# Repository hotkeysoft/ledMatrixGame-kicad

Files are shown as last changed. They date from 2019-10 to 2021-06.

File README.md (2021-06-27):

# LED Matrix Game
Rev A October 2019

### Handheld Electronic Game
- ATmega328PB microcontroller running at 12MHz
- 53 LEDs
- 6 push buttons
- Buzzer
- Tag-Connect for programming
- Runs on 3 AAA batteries

The microcontroller runs a [TMS1000-series emulator](https://github.com/hotkeysoft/emulators) I made.

The Split Second game (by *Parker Brothers*) TMS1400 ROM is loaded on the emulator.

Images
============
|Front | Back |
|---|---|
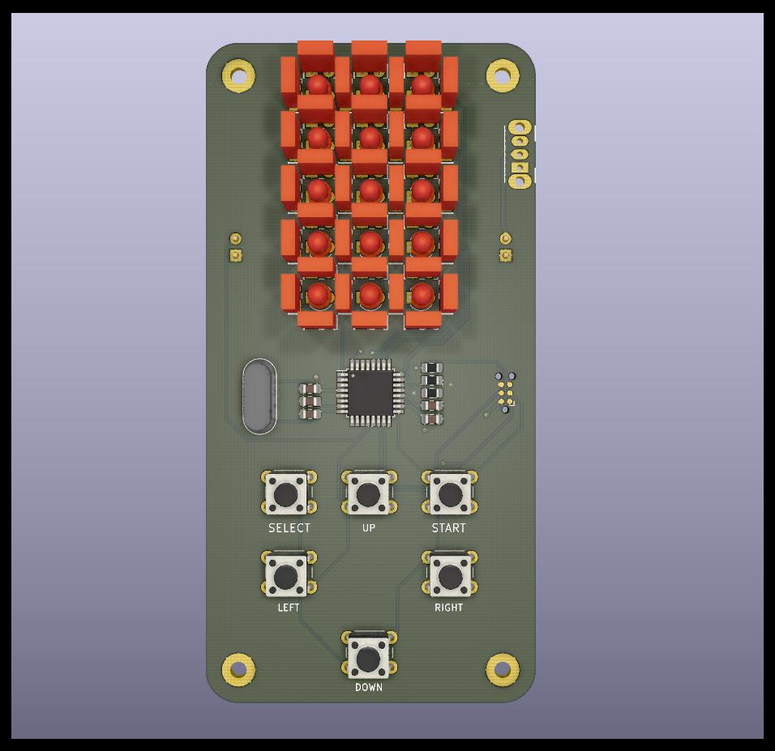
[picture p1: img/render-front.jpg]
Render Front
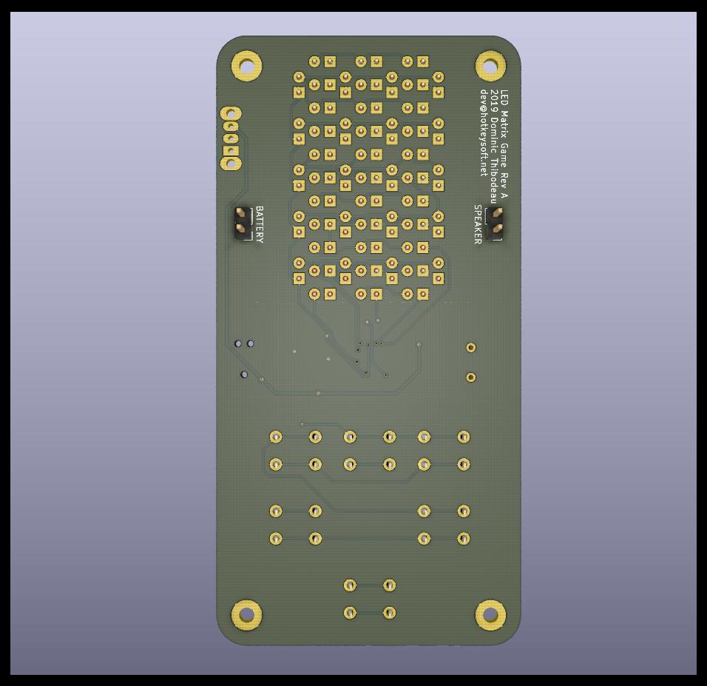
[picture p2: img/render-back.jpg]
Render Back
|||

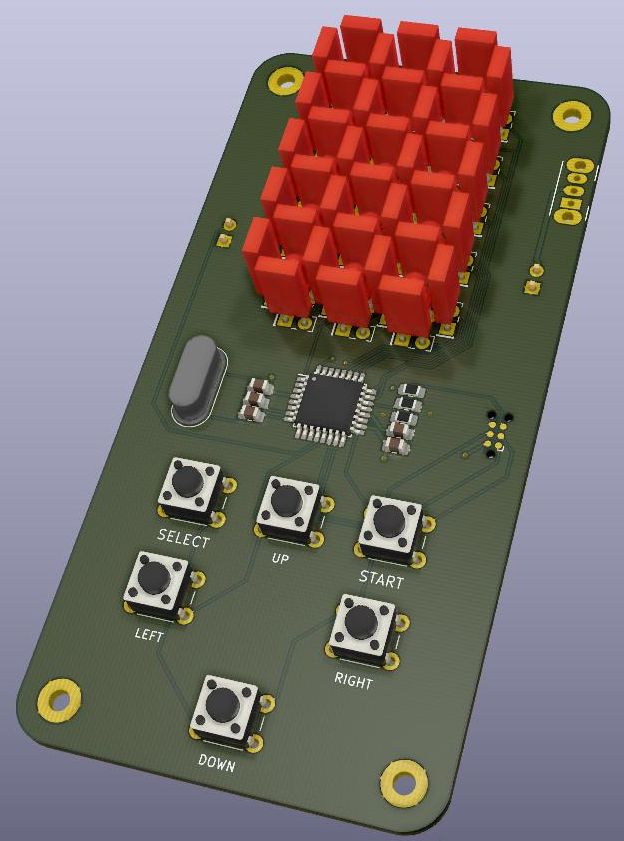
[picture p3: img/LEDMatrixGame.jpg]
Render


### Schematics (pdf)
- [Complete schematics](./img/schema.pdf)

### PCB Images (svg)
- [Top](./img/pcb-front.svg)
- [Bottom](./img/pcb-back.svg)

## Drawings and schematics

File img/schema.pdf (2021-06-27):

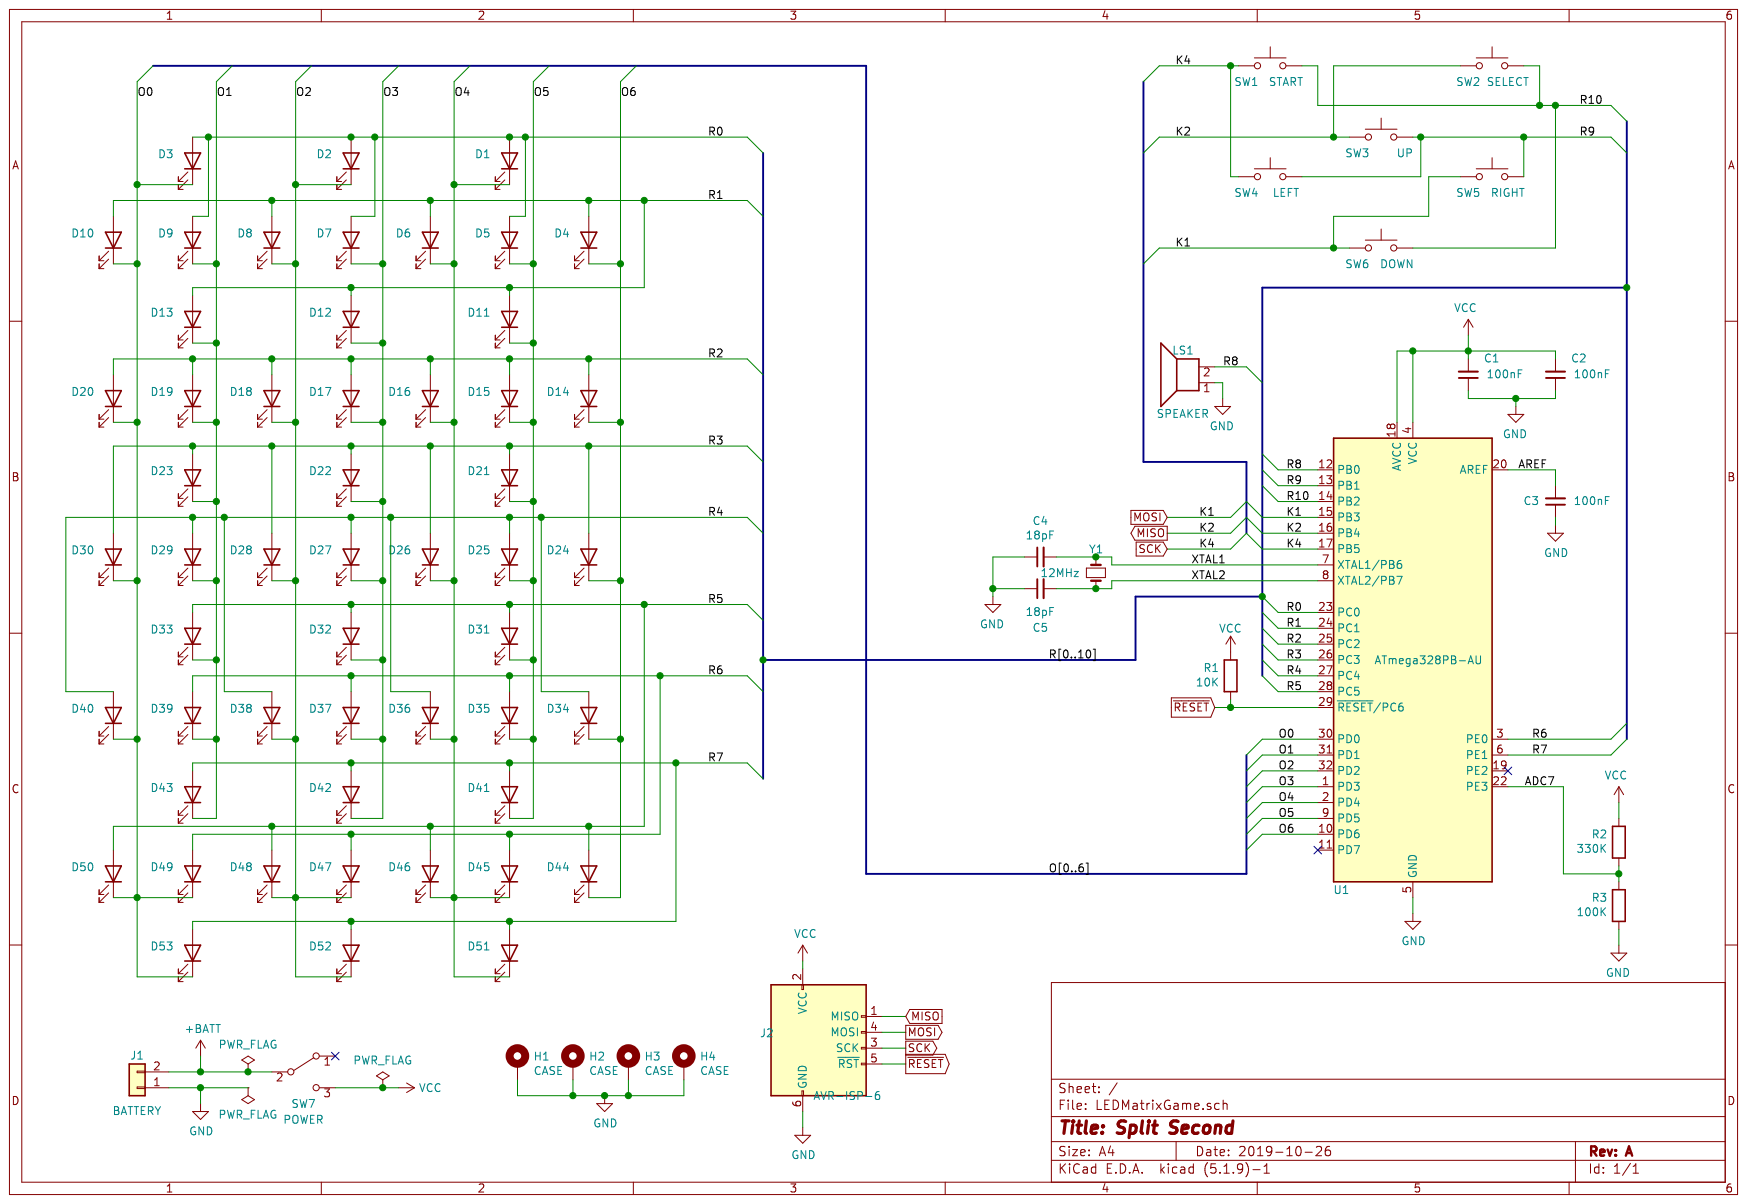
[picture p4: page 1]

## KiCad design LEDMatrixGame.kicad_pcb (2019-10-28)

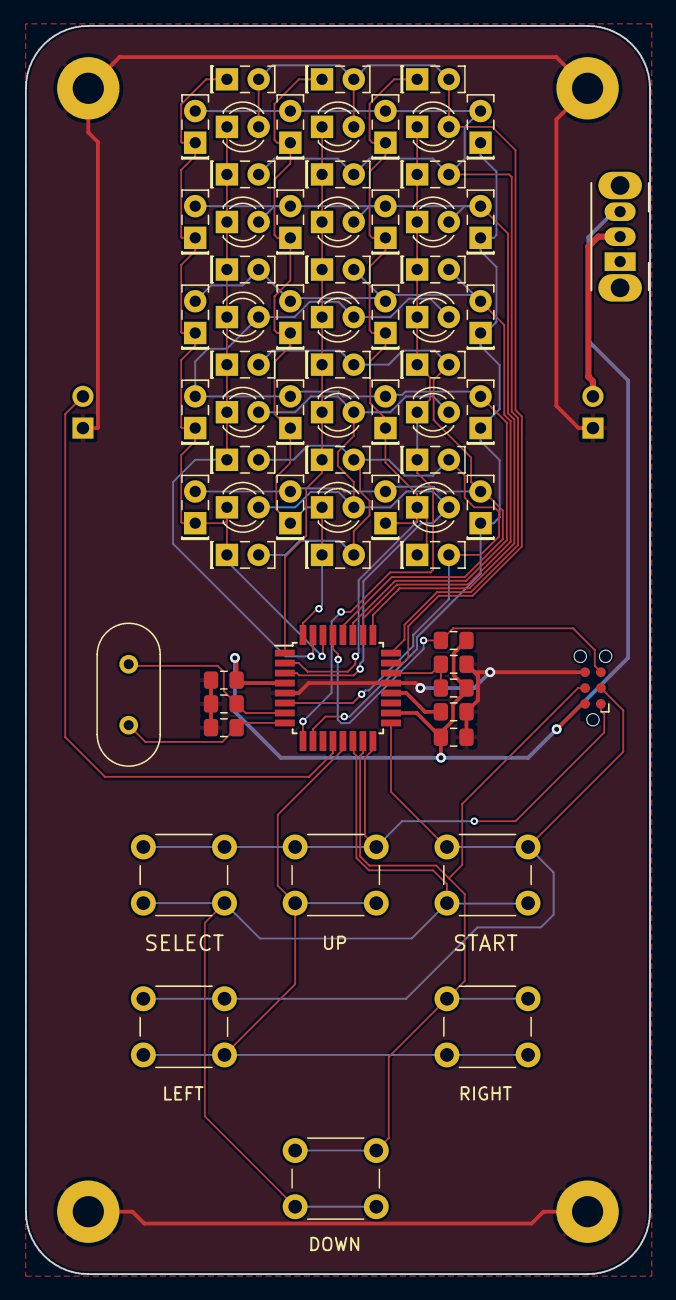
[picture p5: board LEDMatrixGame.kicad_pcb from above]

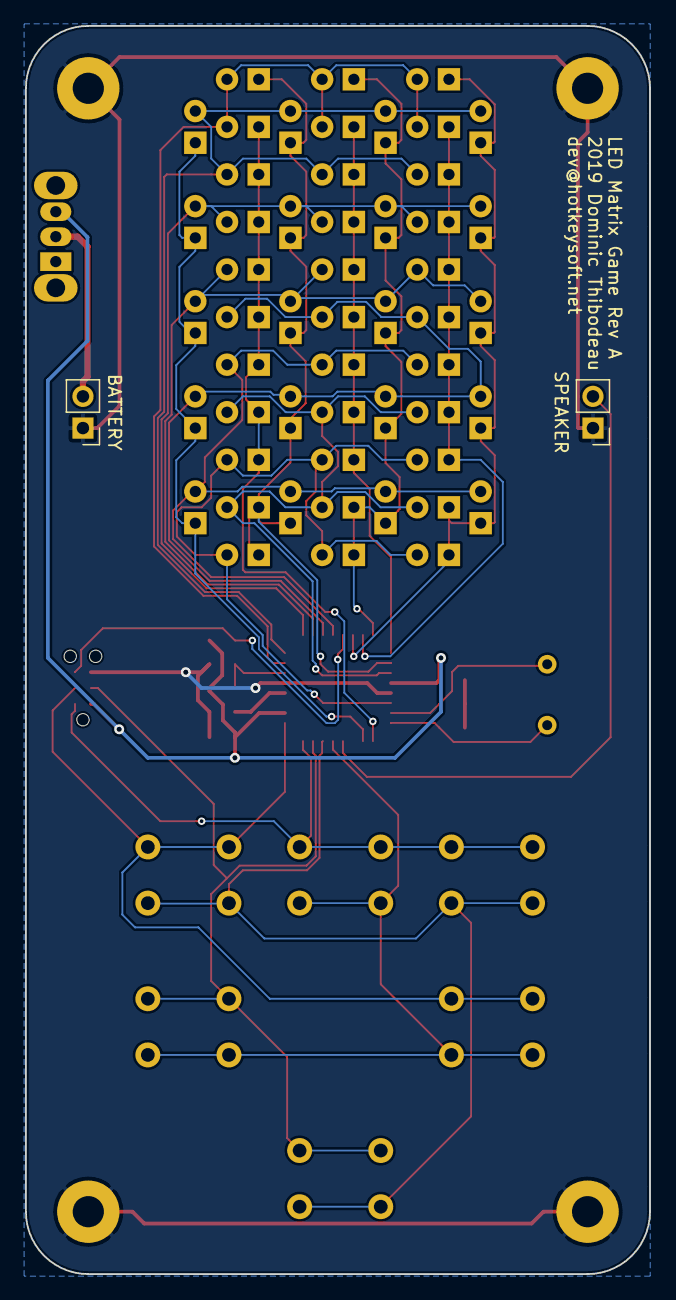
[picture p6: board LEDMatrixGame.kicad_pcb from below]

Board: 2 copper layers, 50.0 x 100.0 mm, 77 parts (2 on the bottom side), 29 nets.

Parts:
C1, C2, C3: 100nF; C_0805_2012Metric_Pad1.15x1.40mm_HandSolder
C4, C5: 18pF; C_0805_2012Metric_Pad1.15x1.40mm_HandSolder
D1, D2, D3, D4, D6, D8, D10, D11, D12, D13, D14, D16, D18, D20, D21, D22, D23, D24, D26, D28, D30, D31, D32, D33, D34, D36, D38, D40, D41, D42, D43, D44, D46, D48, D50, D51, D52, D53: LED_Rectangular_W5.0mm_H2.0mm
D5, D7, D9, D15, D17, D19, D25, D27, D29, D35, D37, D39, D45, D47, D49: LED_D3.0mm
H1, H2, H3, H4: CASE; MountingHole_2.5mm_Pad
J1: BATTERY; PinHeader_1x02_P2.54mm_Vertical
J2: AVR-ISP-6; Tag-Connect_TC2030-IDC-NL_2x03_P1.27mm_Vertical
LS1: SPEAKER; PinHeader_1x02_P2.54mm_Vertical
R1: 10K; R_0805_2012Metric_Pad1.15x1.40mm_HandSolder
R2: 330K; R_0805_2012Metric_Pad1.15x1.40mm_HandSolder
R3: 100K; R_0805_2012Metric_Pad1.15x1.40mm_HandSolder
SW1: START; SW_PUSH_6mm_H5mm
SW2: SELECT; SW_PUSH_6mm_H5mm
SW3: UP; SW_PUSH_6mm_H5mm
SW4: LEFT; SW_PUSH_6mm_H5mm
SW5: RIGHT; SW_PUSH_6mm_H5mm
SW6: DOWN; SW_PUSH_6mm_H5mm
SW7: POWER; SW_CuK_OS102011MA1QN1_SPDT_Angled
U1: ATmega328PB-AU; TQFP-32_7x7mm_P0.8mm
Y1: 12MHz; Crystal_HC49-4H_Vertical

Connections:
+BATT: J1.2, SW7.2
/ADC7: R2.1, R3.2, U1.22
/AREF: C3.2, U1.20
/O0: D3.1, D10.1, D20.1, D30.1, D40.1, D49.1, D50.1, D53.1, U1.30
/O1: D9.1, D13.1, D19.1, D23.1, D29.1, D33.1, D39.1, D43.1, U1.31
/O2: D2.1, D8.1, D18.1, D28.1, D38.1, D47.1, D48.1, D52.1, U1.32
/O3: D7.1, D12.1, D17.1, D22.1, D27.1, D32.1, D37.1, D42.1, U1.1
/O4: D1.1, D6.1, D16.1, D26.1, D36.1, D45.1, D46.1, D51.1, U1.2
/O5: D5.1, D11.1, D15.1, D21.1, D25.1, D31.1, D35.1, D41.1, U1.9
/O6: D4.1, D14.1, D24.1, D34.1, D44.1, U1.10
/R0: D1.2, D2.2, D3.2, D5.2, D7.2, D9.2, U1.23
/R1: D4.2, D6.2, D8.2, D10.2, D11.2, D12.2, D13.2, U1.24
/R2: D14.2, D15.2, D16.2, D17.2, D18.2, D19.2, D20.2, U1.25
/R3: D21.2, D22.2, D23.2, D24.2, D26.2, D28.2, D30.2, U1.26
/R4: D25.2, D27.2, D29.2, D34.2, D36.2, D38.2, D40.2, U1.27
/R5: D31.2, D32.2, D33.2, D44.2, D46.2, D48.2, D50.2, U1.28
/R6: D35.2, D37.2, D39.2, D45.2, D47.2, D49.2, U1.3
/R7: D41.2, D42.2, D43.2, D51.2, D52.2, D53.2, U1.6
/R8: LS1.2, U1.12
/R9: SW3.2, SW4.2, SW5.2, U1.13
/R10: SW1.2, SW2.2, SW6.2, U1.14
/XTAL1: C4.2, U1.7, Y1.1
/XTAL2: C5.2, U1.8, Y1.2
GND: C1.1, C2.1, C3.1, C4.1, C5.1, H1.1, H2.1, H3.1, H4.1, J1.1, J2.6, LS1.1, R3.1, U1.5, U1.21
MISO: J2.1, SW2.1, SW3.1, U1.16
MOSI: J2.4, SW5.1, SW6.1, U1.15
SCK: J2.3, SW1.1, SW4.1, U1.17
VCC: C1.2, C2.2, J2.2, R1.2, R2.2, SW7.3, U1.4, U1.18
~RESET: J2.5, R1.1, U1.29

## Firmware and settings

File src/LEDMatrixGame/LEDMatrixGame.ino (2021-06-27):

#include "rom.h"
#include "TMS1000.h"

#define K1 PIN_PB3
#define K2 PIN_PB4
#define K4 PIN_PB5

#define O0 PIN_PD0
#define O1 PIN_PD1
#define O2 PIN_PD2
#define O3 PIN_PD3
#define O4 PIN_PD4
#define O5 PIN_PD5
#define O6 PIN_PD6

#define R0 PIN_PC0
#define R1 PIN_PC1
#define R2 PIN_PC2
#define R3 PIN_PC3
#define R4 PIN_PC4
#define R5 PIN_PC5
#define R6 PIN_PE0
#define R7 PIN_PE1

const int RPins[] = { R0, R1, R2, R3, R4, R5, R6, R7 };

// Buzzer
#define R8 PIN_PB0

// Buttons
#define R9 PIN_PB1
#define R10 PIN_PB2

// Buttons connected to K1-K4
void inputKCallback() {
      TMS1000::g_cpu.K = ((PINB & 56) ^ 56) >> 3;
}

// LED array connected to R0-R7
// Buzzer connected to R8
// Keypad connected do R9 R10
void outputRCallback(TMS1000::BYTE pin, bool state) {
  switch (pin) {
    case 0: case 1: case 2: case 3:
    case 4: case 5: case 6: case 7:
      digitalWrite(RPins[pin], state);      
    break;
    case 8:
      digitalWrite(R8, state);
      break;
     case 9:
      digitalWrite(R9, !state);     
      break;
     case 10:
     digitalWrite(R10, !state);
    break;
  }
}

// R = LED Anode
// O = LED Cathode
// Ox = 0 to turn on LED
const uint8_t oMap[] = {
  0b11111111, // 0
  0b11111110, // 1
  0b11111101, // 2
  0b11111011, // 3
  0b11110111, // 4
  0b11101111, // 5
  0b11011111, // 6
  0b10111111, // 7
};

void outputOCallback(TMS1000::BYTE val) {
  if (val > 0)
  {
    PORTD = oMap[val & 7];
  }
  else 
  {
    PORTD = 0b11111111;
  }
}

void setup() {
  pinMode(K1, INPUT_PULLUP);
  pinMode(K2, INPUT_PULLUP);
  pinMode(K4, INPUT_PULLUP);

  pinMode(R0, OUTPUT);
  pinMode(R1, OUTPUT);
  pinMode(R2, OUTPUT);
  pinMode(R3, OUTPUT);
  pinMode(R4, OUTPUT);
  pinMode(R5, OUTPUT);
  pinMode(R6, OUTPUT);  
  pinMode(R7, OUTPUT);  

  pinMode(R8, OUTPUT);
  pinMode(R9, OUTPUT);
  pinMode(R10, OUTPUT);

  pinMode(O0, OUTPUT);
  pinMode(O1, OUTPUT);
  pinMode(O2, OUTPUT);
  pinMode(O3, OUTPUT);
  pinMode(O4, OUTPUT);
  pinMode(O5, OUTPUT);
  pinMode(O6, OUTPUT);    
   
  TMS1000::Init(TMS1000::CPU_TMS1400, 4096, 128); 
  TMS1000::SetInputKCallback(inputKCallback);
  TMS1000::SetOutputOCallback(outputOCallback);
  TMS1000::SetOutputRCallback(outputRCallback);
  TMS1000::g_memory.ROM = rom;
  TMS1000::Reset();
}

void loop() {
  TMS1000::Step();
  delayMicroseconds(10);
}
